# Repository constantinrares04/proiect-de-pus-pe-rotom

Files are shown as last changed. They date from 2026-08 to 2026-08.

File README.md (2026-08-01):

# proiect-de-pus-pe-rotom
Dispozitiv pentru gestionare ingrediente si retete.

Foloseste TheMealDB API pentru a obtine retete pe baza ingredientului selectat.
Stocheaza ingredientele valabile intr-o lista.
GUI afisat pe un ecran touchscreen rezistiv.

PCB-ul contine un cip ESP-WROOM-E32, stabilizator de 3.3V, convertor USB-UART.

Utilizare:
	Rotom.cpp si Rotom.h trebuie puse in folder-ul de librarii Arduino, intr-un folder "Rotom"
	User_Setup.h trebuie copiat/mutat in folder-ul librariei TFT-eSPI.

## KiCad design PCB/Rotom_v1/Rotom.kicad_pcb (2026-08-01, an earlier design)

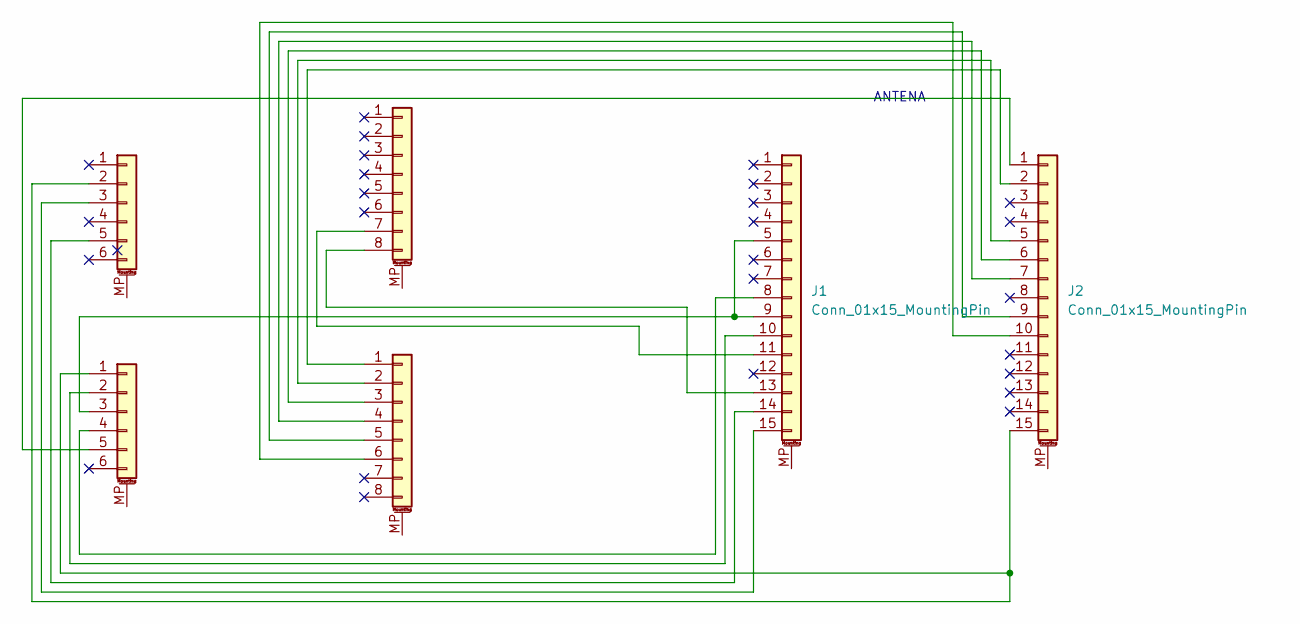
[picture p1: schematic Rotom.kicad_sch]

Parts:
J1, J2: Conn_01x15_MountingPin; PinSocket_1x15_P2.54mm_Vertical
J3, J4: Conn_01x08_MountingPin; PinSocket_1x08_P2.54mm_Vertical
J5, J6: Conn_01x06_MountingPin; PinSocket_1x06_P2.54mm_Vertical

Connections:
unnamed: J1.5, J1.9, J5.3
unnamed: J1.8, J5.4
unnamed: J1.10, J5.2
unnamed: J1.11, J4.7
unnamed: J1.13, J4.8
unnamed: J1.14, J6.5
unnamed: J1.15, J6.3
unnamed: J2.1, J5.5
unnamed: J2.2, J3.1
unnamed: J2.5, J3.2
unnamed: J2.6, J3.3
unnamed: J2.7, J3.4
unnamed: J2.9, J3.5
unnamed: J2.10, J3.6
unnamed: J2.15, J5.1, J6.2

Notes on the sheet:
ANTENA

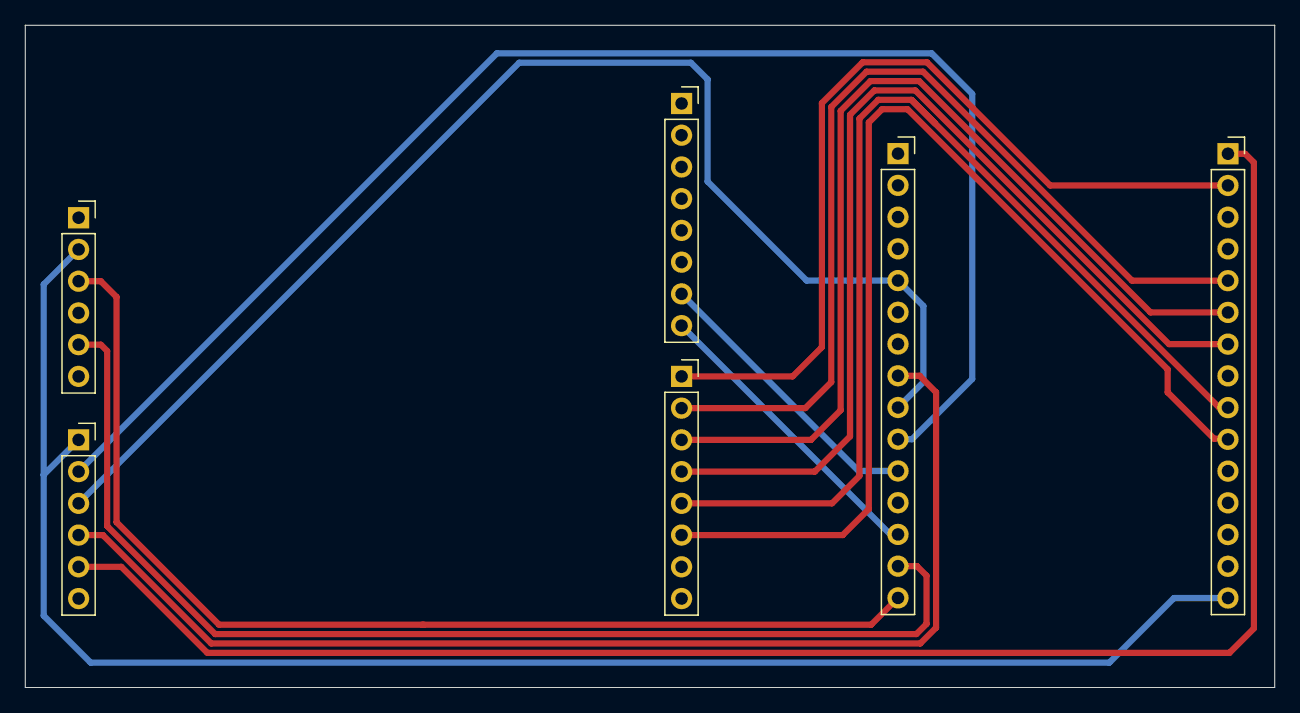
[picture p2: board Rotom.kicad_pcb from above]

Board: 2 copper layers, 100.0 x 53.0 mm, 6 parts (0 on the bottom side), 15 nets.

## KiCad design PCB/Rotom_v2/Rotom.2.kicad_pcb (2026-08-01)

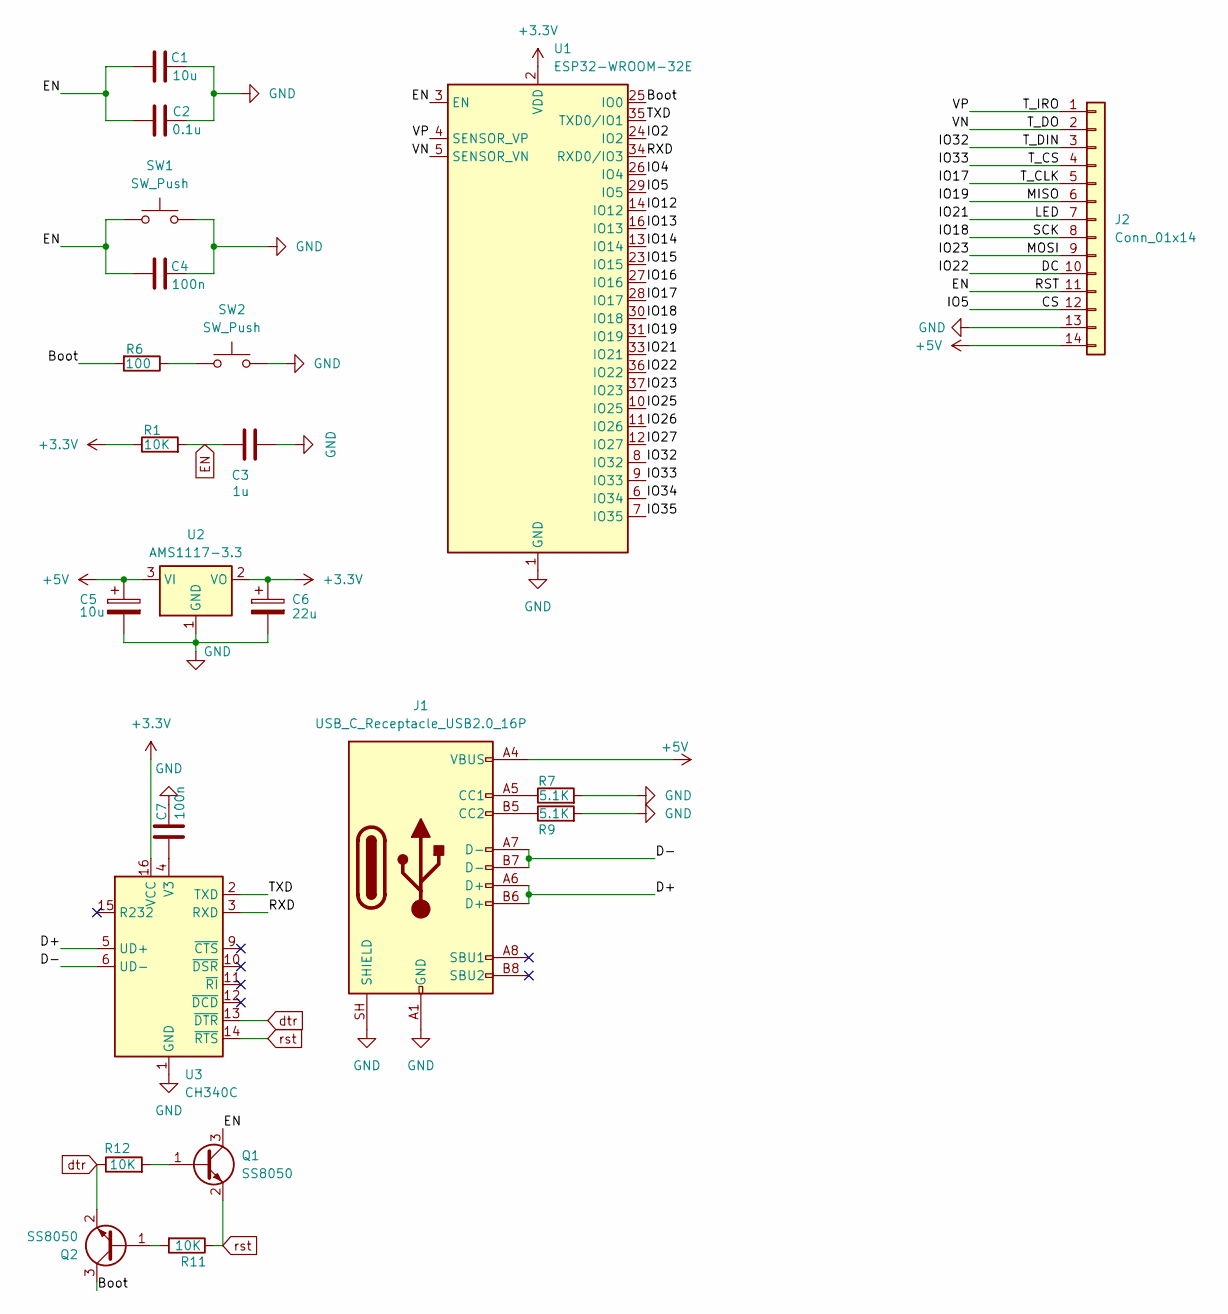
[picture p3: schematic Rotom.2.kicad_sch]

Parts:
C1, C5: 10u; C_0805_2012Metric_Pad1.18x1.45mm_HandSolder
C2: 0.1u; C_0805_2012Metric_Pad1.18x1.45mm_HandSolder
C3: 1u; C_0805_2012Metric_Pad1.18x1.45mm_HandSolder
C4, C7: 100n; C_0805_2012Metric_Pad1.18x1.45mm_HandSolder
C6: 22u; C_0805_2012Metric_Pad1.18x1.45mm_HandSolder
J1: USB_C_Receptacle_USB2.0_16P; USB_C_Receptacle_Amphenol_12401948E412A
J2: Conn_01x14; PinSocket_1x14_P2.54mm_Vertical
Q1, Q2: SS8050; SOT-23
R1, R11, R12: 10K; R_0805_2012Metric_Pad1.20x1.40mm_HandSolder
R6: 100; R_0805_2012Metric_Pad1.20x1.40mm_HandSolder
R7, R9: 5.1K; R_0805_2012Metric_Pad1.20x1.40mm_HandSolder
SW1, SW2: SW_Push; SW_Push_1TS009xxxx-xxxx-xxxx_6x6x5mm
U1: ESP32-WROOM-32E; ESP32-WROOM-32D
U2: AMS1117-3.3; SOT-223-3_TabPin2
U3: CH340C; SOIC-16_3.9x9.9mm_P1.27mm

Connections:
+3.3V: C6.1, R1.1, U1.2 (VDD), U2.2 (VO), U3.16 (VCC)
+5V: C5.1, J1.A4 (VBUS), J1.A9 (VBUS), J1.B4 (VBUS), J1.B9 (VBUS), J2.14, U2.3 (VI)
/Boot: Q2.3 (C), R6.2, U1.25 (IO0)
/CS: J2.12, U1.29 (IO5)
/D+: J1.A6 (D+), J1.B6 (D+), U3.5 (UD+)
/D-: J1.A7 (D-), J1.B7 (D-), U3.6 (UD-)
/DC: J2.10, U1.36 (IO22)
/IO2: U1.24 (IO2)
/IO4: U1.26 (IO4)
/IO12: U1.14 (IO12)
/IO13: U1.16 (IO13)
/IO14: U1.13 (IO14)
/IO15: U1.23 (IO15)
/IO16: U1.27 (IO16)
/IO17: J2.5, U1.28 (IO17)
/IO18: J2.8, U1.30 (IO18)
/IO19: J2.6, U1.31 (IO19)
/IO21: J2.7, U1.33 (IO21)
/IO23: J2.9, U1.37 (IO23)
/IO25: U1.10 (IO25)
/IO26: U1.11 (IO26)
/IO27: U1.12 (IO27)
/IO32: J2.3, U1.8 (IO32)
/IO33: J2.4, U1.9 (IO33)
/IO34: U1.6 (IO34)
/IO35: U1.7 (IO35)
/RXD: U1.34 (RXD0/IO3), U3.3 (RXD)
/TXD: U1.35 (TXD0/IO1), U3.2 (TXD)
/T_DO: J2.2, U1.5 (SENSOR_VN)
/T_IRO: J2.1, U1.4 (SENSOR_VP)
EN: C1.1, C2.1, C3.2, C4.1, J2.11, Q1.3 (C), R1.2, SW1.1, U1.3 (EN)
GND: C1.2, C2.2, C3.1, C4.2, C5.2, C6.2, C7.2, J1.A1 (GND), J1.A12 (GND), J1.B1 (GND), J1.B12 (GND), J1.SH (SHIELD), J2.13, R7.2, R9.2, SW1.2, SW2.2, U1.1 (GND), U1.15 (GND), U1.38 (GND), U1.39 (GND), U2.1 (GND), U3.1 (GND)
unnamed: J1.A5 (CC1), R7.1
unnamed: J1.B5 (CC2), R9.1
unnamed: Q1.1 (B), R12.2
unnamed: Q2.1 (B), R11.2
unnamed: R6.1, SW2.1
unnamed: C7.1, U3.4 (V3)
dtr: Q2.2 (E), R12.1, U3.13 (~DTR)
rst: Q1.2 (E), R11.1, U3.14 (~RTS)

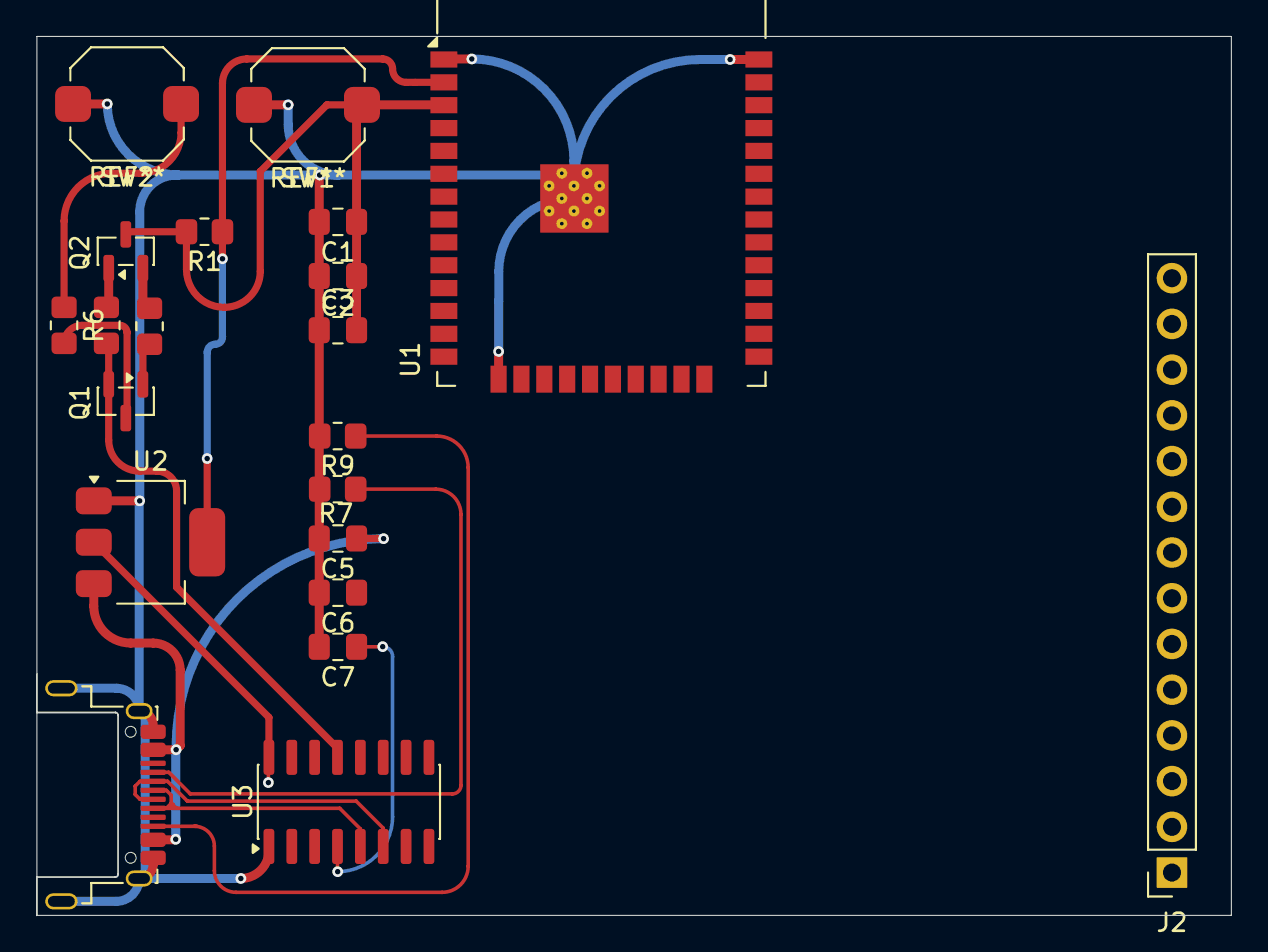
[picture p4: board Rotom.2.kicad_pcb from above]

Board: 2 copper layers, 66.4 x 48.8 mm, 21 parts (0 on the bottom side), 28 nets.

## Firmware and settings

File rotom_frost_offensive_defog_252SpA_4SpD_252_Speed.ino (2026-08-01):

#include "Rotom.h"
#include <LittleFS.h>
#include <TFT_eSPI.h>
#include <lvgl.h>
#include <XPT2046_Touchscreen.h>
#include <WiFi.h>
#include <HTTPClient.h>
#include <Arduino_JSON.h>

SPIClass touchscreenSPI = SPIClass(VSPI);
XPT2046_Touchscreen touchscreen(T_CS, T_IRQ);
#define DRAW_BUF_SIZE (240 * 10 * (LV_COLOR_DEPTH/8))
uint32_t draw_buf[DRAW_BUF_SIZE/4];

int x, y;
Ingredient *ing=nullptr;
lv_obj_t *lbl_name[6]={nullptr};
lv_obj_t *lbl_qnt[6]={nullptr};

//---------------------------------------------------------------------------

lv_obj_t * recipe_win = nullptr;
lv_obj_t * recipe_text_container = nullptr; // Pointer salvat pentru container
lv_obj_t * recipe_label = nullptr;          // Pointer salvat pentru text
JSONVar current_recipe;
bool viewing_instructions = false;

static void recipe_event_handler(lv_event_t * e) {
    lv_event_code_t code = lv_event_get_code(e);
    if(code == LV_EVENT_CLICKED) {
        
        // Verificăm să existe label-ul și containerul în memorie ca să prevenim blocarea
        if(recipe_label == nullptr || recipe_text_container == nullptr) return;

        if(!viewing_instructions) {
            // Trecem la instrucțiuni în siguranță
            lv_label_set_text(recipe_label, (const char*)current_recipe["strInstructions"]);
            
            // Resetăm scroll-ul în sus ca utilizatorul să vadă începutul textului
            lv_obj_scroll_to_y(recipe_text_container, 0, LV_ANIM_OFF);
            viewing_instructions = true;
        } else {
            // Închidem fereastra și curățăm TOȚI pointerii ca să nu lăsăm gunoi în RAM
            lv_obj_del(recipe_win);
            recipe_win = nullptr;
            recipe_text_container = nullptr;
            recipe_label = nullptr;
            viewing_instructions = false;
        }
    }
}

void display_reteta(JSONVar reteta) {
    current_recipe = reteta;
    viewing_instructions = false;

    // Fundalul principal
    recipe_win = lv_obj_create(lv_screen_active());
    lv_obj_set_size(recipe_win, 240, 320);
    lv_obj_center(recipe_win);
    lv_obj_set_style_bg_color(recipe_win, lv_color_hex(0x020414), 0);
    lv_obj_set_style_border_width(recipe_win, 0, 0);
    lv_obj_set_style_radius(recipe_win, 0, 0);
    lv_obj_remove_flag(recipe_win, LV_OBJ_FLAG_SCROLLABLE);

    // Salvarea containerului în variabila globală
    recipe_text_container = lv_obj_create(recipe_win);
    lv_obj_set_size(recipe_text_container, 230, 245); 
    lv_obj_set_pos(recipe_text_container, 5, 10);
    lv_obj_set_style_bg_opa(recipe_text_container, LV_OPA_TRANSP, 0);
    lv_obj_set_style_border_width(recipe_text_container, 0, 0);
    lv_obj_set_style_pad_all(recipe_text_container, 5, 0);
    lv_obj_set_scrollbar_mode(recipe_text_container, LV_SCROLLBAR_MODE_AUTO);

    // Salvarea label-ului în variabila globală
    recipe_label = lv_label_create(recipe_text_container);
    lv_obj_set_width(recipe_label, 210); 
    lv_obj_set_style_text_color(recipe_label, lv_color_hex(0xFFFFFF), 0);
    lv_label_set_long_mode(recipe_label, LV_LABEL_LONG_WRAP);

    // Construim string-ul pentru ingrediente
    String buffer = "";
    if (reteta.hasOwnProperty("strMeal")) {
        buffer += String((const char*)reteta["strMeal"]) + "\n\n";
    }

    for(int i = 1; i <= 20; i++) {
        String prop_ingr = "strIngredient" + String(i);
        String prop_meas = "strMeasure" + String(i);

        if (reteta.hasOwnProperty(prop_ingr.c_str()) && reteta.hasOwnProperty(prop_meas.c_str())) {
            const char* ingr_val = (const char*)reteta[prop_ingr.c_str()];
            const char* meas_val = (const char*)reteta[prop_meas.c_str()];

            if (ingr_val != nullptr && strlen(ingr_val) > 0 && 
                strcmp(ingr_val, "null") != 0 && strcmp(ingr_val, "") != 0) {
                
                String meas_str = (meas_val != nullptr) ? String(meas_val) : "";
                buffer += meas_str + " " + String(ingr_val) + "\n";
            }
        }
    }
    lv_label_set_text(recipe_label, buffer.c_str());

    // Linia decorativă (Y = 265)
    static lv_point_precise_t lin_p1[] = {{10, 265}, {230, 265}};
    lv_obj_t * line = lv_line_create(recipe_win);
    lv_line_set_points(line, lin_p1, 2);
    lv_obj_set_style_line_width(line, 2, 0);
    lv_obj_set_style_line_color(line, lv_color_hex(0x3B3B3B), 0);

    // Butonul de navigare sub linie
    lv_obj_t * btn = lv_button_create(recipe_win);
    lv_obj_set_size(btn, 150, 30);
    lv_obj_set_pos(btn, 45, 272);
    lv_obj_set_style_bg_color(btn, lv_color_hex(0x4F46E5), 0);
    lv_obj_add_event_cb(btn, recipe_event_handler, LV_EVENT_CLICKED, NULL);

    // Textul ">" din interiorul butonului
    lv_obj_t * btn_lbl = lv_label_create(btn);
    lv_label_set_text(btn_lbl, "Urmatoarea Pagina");
    lv_obj_center(btn_lbl);
    lv_obj_set_style_text_color(btn_lbl,lv_color_hex(0xFFFFFF),0);
}

void get_reteta(String id) {
    // Curățăm eventualele spații accidentale din ID
    id.trim();
    if (id.length() == 0) {
        Serial.println("Eroare: ID-ul pentru lookup este gol!");
        return;
    }

    HTTPClient http;
    // Construim URL-ul folosind String pentru a evita erorile de buffer
    String url = "https://www.themealdb.com/api/json/v1/1/lookup.php?i=" + id;
    
    Serial.print("Pasul 2: Lansare lookup catre: ");
    Serial.println(url);
    
    http.begin(url);
    int httpCode = http.GET();
    
    if (httpCode == HTTP_CODE_OK) {
        String payload = http.getString();
        JSONVar json_data = JSON.parse(payload);
        
        if (JSON.typeof(json_data) != "undefined" && json_data.hasOwnProperty("meals")) {
            display_reteta(json_data["meals"][0]);
        } else {
            Serial.println("Eroare: Structura JSON lookup invalida.");
        }
    } else {
        Serial.printf("Eroare HTTP Lookup esuata! Cod eroare: %d\n", httpCode);
        // Dacă primești cod negativ (ex: -1), înseamnă că ESP32 a pierdut conexiunea WiFi temporar
    }
    http.end();
}

void get_retete_lista() {
    if (ing == nullptr) {
        Serial.println("Eroare: Nu exista ingredient selectat.");
        return;
    }

    HTTPClient http;
    String url = "https://www.themealdb.com/api/json/v1/1/filter.php?i=" + String(ing->Get_ID());
    
    Serial.print("Pasul 1: Lansare filtru catre: ");
    Serial.println(url);
    
    http.begin(url);
    int httpCode = http.GET();
    
    String id_gasit = ""; // Stocăm ID-ul local aici

    if (httpCode == HTTP_CODE_OK) {
        String payload = http.getString();
        JSONVar json_data = JSON.parse(payload);
        
        if (JSON.typeof(json_data) != "undefined" && json_data.hasOwnProperty("meals") && json_data["meals"].length() > 0) {
            if (json_data["meals"][0].hasOwnProperty("idMeal")) {
                id_gasit = String((const char*)json_data["meals"][0]["idMeal"]);
                Serial.printf("ID extras cu succes: %s\n", id_gasit.c_str());
            }
        } else {
            Serial.println("Nu s-au gasit retete pentru acest ingredient.");
        }
    } else {
        Serial.printf("Eroare HTTP Filtrare esuata! Cod eroare: %d\n", httpCode);
    }
    
    http.end(); // Inchidem complet prima conexiune si eliberam memoria

    // Trimitem cererea de lookup DOAR dacă am extras un ID valid la pasul 1
    if (id_gasit.length() > 0) {
        delay(50); // Mică pauză necesară pentru ca stiva de rețea a ESP32 să respire
        get_reteta(id_gasit);
    }
}
//---------------------------------------------------------------------------

void touchscreen_read(lv_indev_t * indev, lv_indev_data_t * data){
  if(touchscreen.tirqTouched() && touchscreen.touched()) {
    TS_Point p = touchscreen.getPoint();
    x = map(p.x, 200, 3700, 1, 240);
    y = map(p.y, 240, 3800, 1, 320);
    data->state = LV_INDEV_STATE_PRESSED;
    data->point.x = x;
    data->point.y = y;
  }
  else {
    data->state = LV_INDEV_STATE_RELEASED;
  }
}

static void event_handler_btn(lv_event_t * e) {
  lv_event_code_t code = lv_event_get_code(e);
  if(code == LV_EVENT_CLICKED) {
    int i=(int)lv_event_get_user_data(e);
    char temp[12];
    if(i==0){
      ing = ing->Prev();
    }else if(i==1){
      ing = ing->Next();
    }else if(i==2){
      get_retete_lista();
      return;
    }
    Ingredient *point = ing;
    for(int i = 0; i < 6; i++){
      lv_label_set_text(lbl_name[i], point->Get_Name());
      lv_label_set_text(lbl_qnt[i], itoa(point->Get_Qnt(), temp, 10));
      point = point->Next();
    }
  }
}

void create_GUI(){
  lv_obj_t * lcd = lv_screen_active();
  lv_obj_set_style_bg_color(lcd,lv_color_hex(0x020414),0);
  const char* btn_labels[]={LV_SYMBOL_UP,LV_SYMBOL_DOWN,"Reteta"};
  for(int i=0;i<3;i++){
    lv_obj_t * btn = lv_button_create(lcd);
    lv_obj_set_size(btn, 60, 30);
    lv_obj_set_pos(btn, i*75+15, 280);
    lv_obj_set_style_bg_color(btn, lv_color_hex(0x4F46E5), 0);
    lv_obj_add_event_cb(btn, event_handler_btn, LV_EVENT_CLICKED, (void*)i);

    lv_obj_t * lbl_btn=lv_label_create(btn);
    lv_label_set_text(lbl_btn, btn_labels[i]);
    lv_obj_center(lbl_btn);
    lv_obj_set_style_text_color(lbl_btn,lv_color_hex(0xFFFFFF),0);
  }

  char temp[12];
  Ingredient *point=ing;
  for(int i=0;i<6;i++){
    lbl_name[i]=lv_label_create(lcd);
    lv_obj_set_size(lbl_name[i], 150, 20);
    lv_obj_set_pos(lbl_name[i], 30, i*35+45);
    lv_label_set_long_mode(lbl_name[i], LV_LABEL_LONG_SCROLL);
    lv_obj_set_style_text_color(lbl_name[i],lv_color_hex(0xFFFFFF),0);

    lbl_qnt[i]=lv_label_create(lcd);
    lv_obj_set_size(lbl_qnt[i], 30, 20);
    lv_obj_set_pos(lbl_qnt[i], 200, i*35+45);
    lv_obj_set_style_text_color(lbl_qnt[i],lv_color_hex(0xFFFFFF),0);

    lv_label_set_text(lbl_name[i], point->Get_Name());
    lv_label_set_text(lbl_qnt[i], itoa(point->Get_Qnt(), temp, 10));

    point=point->Next();
  }

  lv_obj_t *lbl_point=lv_label_create(lcd);
  lv_obj_set_size(lbl_point, 25, 25);
  lv_obj_set_pos(lbl_point, 10, 44);
  lv_label_set_text(lbl_point,LV_SYMBOL_RIGHT);

  static lv_point_precise_t lin_p1[]={{10,265},{230,265}};
  static lv_point_precise_t lin_p2[]={{10,17},{230,17}};

  lv_obj_t *lin_1=lv_line_create(lcd);
  lv_obj_t *lin_2=lv_line_create(lcd);
  lv_line_set_points(lin_1,lin_p1,2);
  lv_line_set_points(lin_2,lin_p2,2);
  lv_obj_set_style_line_width(lin_1, 2, 0);
  lv_obj_set_style_line_width(lin_2, 2, 0);
  lv_obj_set_style_line_color(lin_1,lv_color_hex(0xFFFFFF),0);
  lv_obj_set_style_line_color(lin_2,lv_color_hex(0xFFFFFF),0);
}

void pornire_wifi(){
  WiFi.mode(WIFI_STA);
  WiFi.begin("Rares","123456789");
  while(WiFi.status()!= WL_CONNECTED){
    delay(500);
  }
  //WiFi.setTxPower(WiFi_POWER_19_5dBm);// multumim contului espboards, daca e activat consum de 3 orei mai multa putere, dar obtine ~4,5dBm
  return;
}

void setup(){
Serial.begin(115200);

  LittleFS.begin();
  Get_List(ing,"/data.txt");
  LittleFS.end();

  lv_init();
  touchscreenSPI.begin(T_CLK, T_DO, T_DIN, T_CS);
  touchscreen.begin(touchscreenSPI);

  lv_display_t *disp=lv_tft_espi_create(240, 320, draw_buf, sizeof(draw_buf));
  lv_indev_t * indev = lv_indev_create();
  lv_indev_set_type(indev, LV_INDEV_TYPE_POINTER);
  lv_indev_set_read_cb(indev, touchscreen_read);

  pornire_wifi();
  create_GUI();
}

void loop(){
  lv_task_handler();
  lv_tick_inc(20);
  delay(20); 
}
